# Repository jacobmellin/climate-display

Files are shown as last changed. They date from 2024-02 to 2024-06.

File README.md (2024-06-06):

# 3D Printed Room Climate Display/Controller based on ESP32/Arduino

Let's [Stoßlüft](https://www.youtube.com/watch?v=y79x2q360W8)!

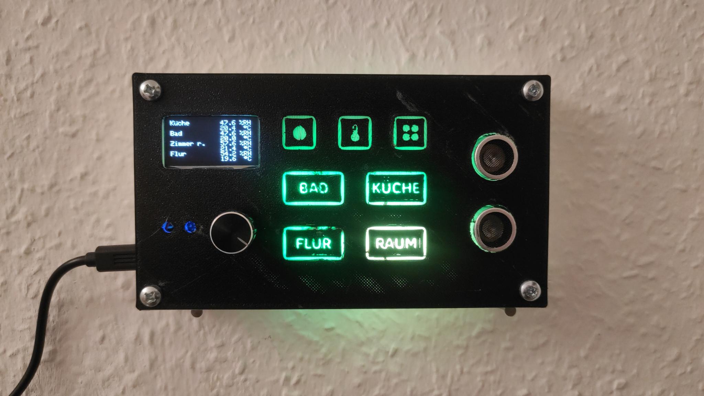
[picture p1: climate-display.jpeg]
Climate Display: preview image of printed device


The DIY Climate Display/Controller thing can do the following:

- Shows Temperature and Relative Humidity information for 4 different rooms at once!
- Can be controlled via MQTT/WiFi, so you can for example setup Home Assistant to set Temperature/Humidity Information
- Will light colored LEDs to tell you when Humidity/Temperature in a room rises above a certain threshold (e. g. Yellow: 57%, Red: 60%).
- Notifies you when you forget to close the windows
- Allows you to set the temperature for your smart thermostats via MQTT

## Components

| Qty. | Component Type | Specific Component used | Est. Price (USD) | Est. Price (€) | Example Shop link (DE) | |
|---|---|---|---|---|---|---|
| 2m | Wire in 3 different colors | | | | | |
|  1x  | ESP32 Development Board | ESP32 Lolin32 Lite | | € 8,99 | https://www.az-delivery.de/en/products/esp32-lolin-lolin32 | |
|  1x  | Ultrasonic Distance Sensor | HC-SR04 | | | | |
|  1x  | OLED Display | SH1106 (128x64) | | | | |
|  7x  | Addressible RGB LED | WSB2812B | | | | |
|  1x  | Rotary Encoder | | | | | |
|  2x  | Push Button (optional) | | | | | |
| 2x | 1K Metal Film resistor | | | | | |
| 1x | USB Power Supply / Micro USB Cable | | | | | |

## Printing & Assembly

TODO

## Configuring & Programming

TODO

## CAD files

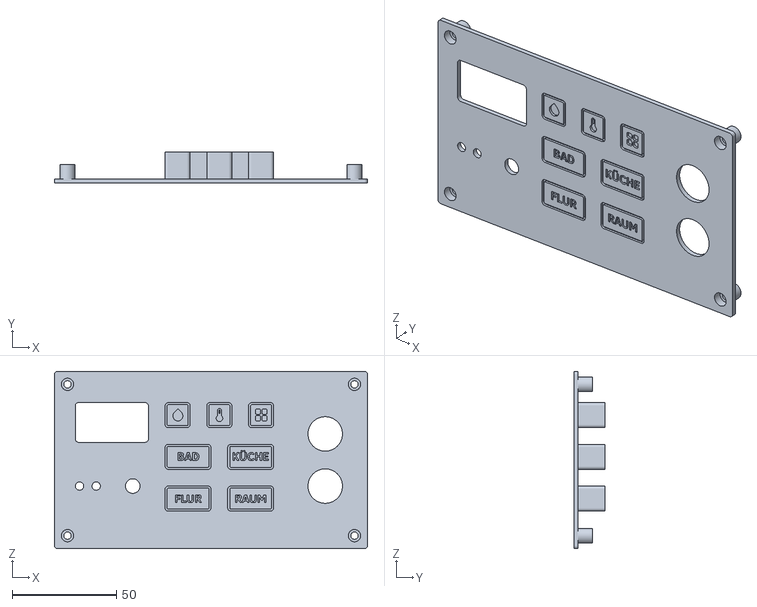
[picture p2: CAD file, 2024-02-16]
cad/ClimateDisplay-Cover.stl
150.0 x 15.0 x 85.0

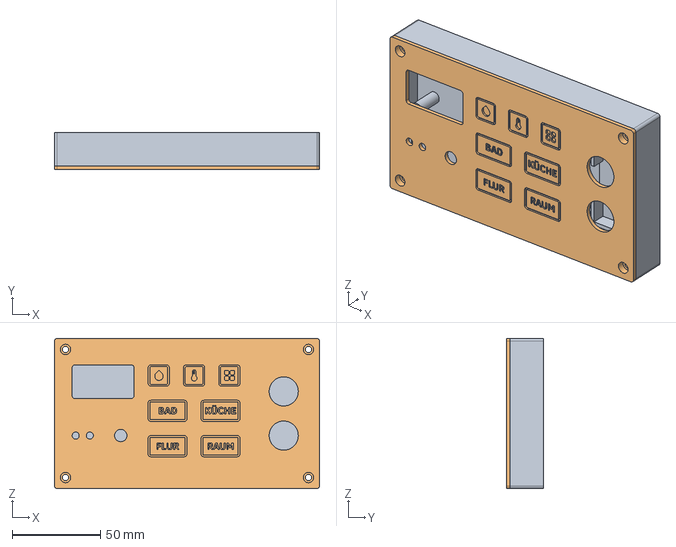
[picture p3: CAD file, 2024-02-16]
cad/ClimateDisplay.FCStd
150.0 x 21.0 x 85.0 mm
Cover

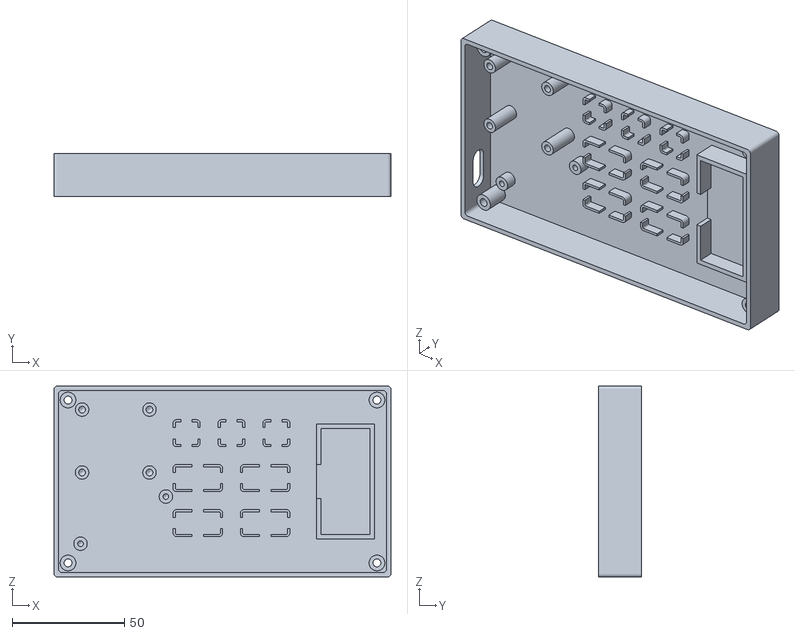
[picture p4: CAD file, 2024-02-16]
cad/ClimateDisplay-Box.stl
150.0 x 19.0 x 85.0

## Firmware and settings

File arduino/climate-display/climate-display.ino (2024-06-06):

#include <WiFi.h>
#include <WiFiClient.h>
#include <WebServer.h>
#include <ESPmDNS.h>
#include <Update.h>
#include <PubSubClient.h>
#include <SPI.h>
#include <Wire.h>
#include <Adafruit_GFX.h>
#include <Adafruit_SH110X.h>
#include <InputDebounce.h>
#include <NewEncoder.h>
#include <HCSR04.h>
#include <arduino-timer.h>

#include <FastLED.h>

const char* host = "esp32";
const char* ssid = "AhoyThereCastaways";
const char* password = "97755056664745005086";

const char* mqtt_server = "192.168.178.43";

#include "web.h"
#include "ClimateDisplay.h"

#define LED_PIN 2
#define NUM_LEDS 7
#define ROTARY_PIN_A 16
#define ROTARY_PIN_B 17
#define BUTTON1_PIN 18
#define US_SENSOR_PIN_ECHO 15
#define US_SENSOR_PIN_TRIG 13
#define PIN_SCK 22
#define PIN_SDA 19

#define SCREEN_WIDTH 128
#define SCREEN_HEIGHT 64
#define OLED_RESET -1
#define SCREEN_ADDRESS 0x3C

#define BUTTON_DEBOUNCE_DELAY 50

auto timer = timer_create_default();

Adafruit_SH1106G display(SCREEN_WIDTH, SCREEN_HEIGHT, &Wire, OLED_RESET);

WebServer server(80);
CRGB leds[NUM_LEDS];
ClimateDisplay climateDisplay(leds, &display);

NewEncoder encoder(ROTARY_PIN_A, ROTARY_PIN_B, -20, 20, 0, 0);
int16_t prevEncoderValue;

static InputDebounce button1;

HCSR04 hc(US_SENSOR_PIN_TRIG, US_SENSOR_PIN_ECHO);
float hcCurrentDist;

WiFiClient espClient;
PubSubClient client(espClient);
long lastMsg = 0;
char msg[50];
int value = 0;

void callback(char* topic, byte* payload, unsigned int length) {
    Serial.print("Message arrived [");
    Serial.print(topic);
    Serial.print("] ");
    for (int i = 0; i < length; i++) {
        Serial.print((char)payload[i]);
    }
    Serial.println();

    // TODO: Do a better job of parsing this
    if(std::string(topic) == "climatedisplay/kitchen/humidity") {
        float humidity = atof((char*)payload);
        climateDisplay.setRoomHumidity(Room::Kitchen, atof((char*)payload));
    } else if(std::string(topic) == "climatedisplay/kitchen/temperature") {
        float temperature = atof((char*)payload);
        climateDisplay.setRoomTemperature(Room::Kitchen, atof((char*)payload));
    } else if(std::string(topic) == "climatedisplay/bathroom/humidity") {
        float humidity = atof((char*)payload);
        climateDisplay.setRoomHumidity(Room::Bathroom, atof((char*)payload));
    } else if(std::string(topic) == "climatedisplay/bathroom/temperature") {
        float temperature = atof((char*)payload);
        climateDisplay.setRoomTemperature(Room::Bathroom, atof((char*)payload));
    } else if(std::string(topic) == "climatedisplay/bedroom/humidity") {
        float humidity = atof((char*)payload);
        climateDisplay.setRoomHumidity(Room::Bedroom, atof((char*)payload));
    } else if(std::string(topic) == "climatedisplay/bedroom/temperature") {
        float temperature = atof((char*)payload);
        climateDisplay.setRoomTemperature(Room::Bedroom, atof((char*)payload));
    } else if(std::string(topic) == "climatedisplay/corridor/humidity") {
        float humidity = atof((char*)payload);
        climateDisplay.setRoomHumidity(Room::Corridor, atof((char*)payload));
    } else if(std::string(topic) == "climatedisplay/corridor/temperature") {
        float temperature = atof((char*)payload);
        climateDisplay.setRoomTemperature(Room::Corridor, atof((char*)payload));
    }
}

void reconnect() {
    // Loop until we're reconnected
    while (!client.connected()) {
        Serial.print("Attempting MQTT connection...");
        // Attempt to connect
        if (client.connect("ESP32Client", "mosquitto", "mosquitto")) {
            Serial.println("connected");

            client.subscribe("climatedisplay/kitchen/humidity");
            client.subscribe("climatedisplay/kitchen/temperature");
            client.subscribe("climatedisplay/bedroom/humidity");
            client.subscribe("climatedisplay/bedroom/temperature");
            client.subscribe("climatedisplay/bathroom/humidity");
            client.subscribe("climatedisplay/bathroom/temperature");
            client.subscribe("climatedisplay/corridor/humidity");
            client.subscribe("climatedisplay/corridor/temperature");
        } else {
            Serial.print("failed, rc=");
            Serial.print(client.state());
            Serial.println(" try again in 5 seconds");
            // Wait 5 seconds before retrying
            delay(5000);
        }
    }
}

void knobCallback(long value) {
    Serial.printf("Value: %i\n", value);
}

/*
 * setup function
 */
void setup(void) {
   pinMode(2, OUTPUT);
   FastLED.addLeds<WS2812B, LED_PIN, GRB>(leds, NUM_LEDS);

  Serial.begin(115200);

  // Connect to WiFi network
  WiFi.begin(ssid, password);
  Serial.println("");

  // Wait for connection
  while (WiFi.status() != WL_CONNECTED) {
    delay(500);
    Serial.print(".");
  }
  Serial.println("");
  Serial.print("Connected to ");
  Serial.println(ssid);
  Serial.print("IP address: ");
  Serial.println(WiFi.localIP());

  // MQTT Setup
  client.setServer(mqtt_server, 1883);
  client.setCallback(callback);

  /*use mdns for host name resolution*/
  if (!MDNS.begin(host)) { //http://esp32.local
    Serial.println("Error setting up MDNS responder!");
    while (1) {
      delay(1000);
    }
  }
  Serial.println("mDNS responder started");
  /*return index page which is stored in serverIndex */
  server.on("/", HTTP_GET, []() {
    server.sendHeader("Connection", "close");
    server.send(200, "text/html", loginIndex);
  });
  server.on("/serverIndex", HTTP_GET, []() {
    server.sendHeader("Connection", "close");
    server.send(200, "text/html", serverIndex);
  });
  /*handling uploading firmware file */
  server.on("/update", HTTP_POST, []() {
    server.sendHeader("Connection", "close");
    server.send(200, "text/plain", (Update.hasError()) ? "FAIL" : "OK");
    ESP.restart();
  }, []() {
    HTTPUpload& upload = server.upload();
    if (upload.status == UPLOAD_FILE_START) {
      Serial.printf("Update: %s\n", upload.filename.c_str());
      if (!Update.begin(UPDATE_SIZE_UNKNOWN)) { //start with max available size
        Update.printError(Serial);
      }
    } else if (upload.status == UPLOAD_FILE_WRITE) {
      /* flashing firmware to ESP*/
      if (Update.write(upload.buf, upload.currentSize) != upload.currentSize) {
        Update.printError(Serial);
      }
    } else if (upload.status == UPLOAD_FILE_END) {
      if (Update.end(true)) { //true to set the size to the current progress
        Serial.printf("Update Success: %u\nRebooting...\n", upload.totalSize);
      } else {
        Update.printError(Serial);
      }
    }
  });

  server.begin();

  // MQTT and Web Timers
  timer.every(1, [](void *arg) -> bool {
    server.handleClient();
    if (!client.connected()) {
      reconnect();
    }
    client.loop();
    return true;
  });


  // Setup OLED
  Wire.begin(PIN_SCK, PIN_SDA);
  if(!display.begin(SCREEN_ADDRESS, true)) {
    Serial.println(F("SH1106: Allocation failed"));
    for(;;);
  }

  // Setup Button
  pinMode(BUTTON1_PIN, INPUT);
  button1.registerCallbacks(nullptr, [](uint8_t pin) {
  });
  button1.setup(BUTTON1_PIN, BUTTON_DEBOUNCE_DELAY, InputDebounce::PIM_INT_PULL_UP_RES);
  timer.every(3, [](void *arg) -> bool {
      unsigned long currentMillis = millis();
      button1.process(currentMillis);
      return true;
  });

  // Setup Climate Display
  climateDisplay.setRoomHumidity(Room::Bedroom, 80);
  climateDisplay.setRoomHumidity(Room::Corridor, 80);

  // Setup rotary encoder
  pinMode(ROTARY_PIN_A, INPUT_PULLUP);
  pinMode(ROTARY_PIN_B, INPUT_PULLUP);
  encoder.begin();
  timer.every(10, [](void *arg) -> bool {
    int16_t currentValue;
    NewEncoder::EncoderState currentEncoderState;

      if(encoder.getState(currentEncoderState)) {
        Serial.println("Encoder: ");
        currentValue = currentEncoderState.currentValue;

        // Handle big jumps
        if(currentValue > (prevEncoderValue + 1)) {
            currentValue = prevEncoderValue + 1;
        } else if(currentValue < (prevEncoderValue - 1)) {
            currentValue = prevEncoderValue - 1;
        }

        prevEncoderValue = currentValue;
        Serial.println(currentValue);
      }     
      return true;
    });

    // Ultrasonic Distance Sensor
    timer.every(250, [](void *arg) -> bool {
      float dist = hc.dist();
      climateDisplay.setUserDistance(dist);
      climateDisplay.loop();
      Serial.println(hc.dist());
      return true;
    });

    // Display loop
    timer.every(50, [](void*arg) -> bool {
         climateDisplay.loop();
         return true;
    });

}

void loop(void) {
  timer.tick();
}

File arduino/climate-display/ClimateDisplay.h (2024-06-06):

#include <map>
#include <FastLED.h>
#include <Adafruit_GFX.h>
#include <Adafruit_SH110X.h>
#include <string>
#include <iomanip>
#include <sstream>

#define LED_FADE_DURATION_MS 1000
#define STANDBY_TIMEOUT_MS 10000

enum class Room
{
    Kitchen,
    Bathroom,
    Bedroom,
    Corridor
};

enum class LED
{
    Kitchen,
    Bathroom,
    Bedroom,
    Corridor,
    Window,
    Humidity,
    Temperature
};

class ClimateDisplay {
    private:
        struct RoomData {
            Room room;
            const char* name;
            float temperature;
            float humidity;
            bool windowOpen;
            LED led;
        };

        struct LEDData {
            int ledIndex;
            CRGB color;
            CRGB fromColor;
            CRGB toColor;
            int fadeStart;
            float fadeProgress;
            bool isFading;
        };

        std::map<Room, RoomData> rooms; 
        std::map<LED, LEDData> displayLEDs;

        CRGB* leds;
        Adafruit_SH1106G* display;
        bool isStandby = false;
        float humidityWarningThreshold = 55;
        float humiditiyCriticalThreshold = 60;
        float temperatureCriticalThreshold = 19;
        float userDistance = 0;
        float userDistanceThreshold = 40;

        float startWakeTime = 0;

        void replaceSpecialChars(const char* text) {
            for (int i = 0; i < sizeof(text); i++) {
            }
        }

        void handleLEDFade() {
            for(auto& led : displayLEDs) {
                if(led.second.isFading) {
                    led.second.fadeProgress = 
                        float(millis() - led.second.fadeStart) / LED_FADE_DURATION_MS;
                    if(led.second.fadeProgress >= 1) {
                        led.second.isFading = false;
                        led.second.color = led.second.toColor;
                    } else {
                        led.second.color = blend(
                                led.second.fromColor,
                                led.second.toColor,
                                led.second.fadeProgress*255);
                    }
                    leds[led.second.ledIndex] = led.second.color;
                    FastLED.show();
                }
            }
        }

    public:
        ClimateDisplay(CRGB* leds, Adafruit_SH1106G* display) {
            this->leds = leds;
            this->display = display;

            displayLEDs[LED::Kitchen] = LEDData();
            displayLEDs[LED::Kitchen].ledIndex = 3;
            displayLEDs[LED::Kitchen].color = CRGB::Black;

            displayLEDs[LED::Bathroom] = LEDData();
            displayLEDs[LED::Bathroom].ledIndex = 4;
            displayLEDs[LED::Bathroom].color = CRGB::Black;


            displayLEDs[LED::Corridor] = LEDData();
            displayLEDs[LED::Corridor].ledIndex = 5;
            displayLEDs[LED::Corridor].color = CRGB::Black;

            displayLEDs[LED::Bedroom] = LEDData();
            displayLEDs[LED::Bedroom].ledIndex = 6;
            displayLEDs[LED::Bedroom].color = CRGB::Black;

            displayLEDs[LED::Window] = LEDData();
            displayLEDs[LED::Window].ledIndex = 2;
            displayLEDs[LED::Window].color = CRGB::Black;

            displayLEDs[LED::Humidity] = LEDData();
            displayLEDs[LED::Humidity].ledIndex = 0;
            displayLEDs[LED::Humidity].color = CRGB::Black;
            
            displayLEDs[LED::Temperature] = LEDData();
            displayLEDs[LED::Temperature].ledIndex = 0;
            displayLEDs[LED::Temperature].color = CRGB::Black;

            rooms[Room::Kitchen] = RoomData();
            rooms[Room::Kitchen].room = Room::Kitchen;
            rooms[Room::Kitchen].led = LED::Kitchen;
            rooms[Room::Kitchen].name = "K\201che";

            rooms[Room::Bathroom] = RoomData();
            rooms[Room::Bathroom].room = Room::Bathroom;
            rooms[Room::Bathroom].led = LED::Bathroom;
            rooms[Room::Bathroom].name = "Bad";

            rooms[Room::Bedroom] = RoomData();
            rooms[Room::Bedroom].room = Room::Bedroom;
            rooms[Room::Bedroom].led = LED::Bedroom;
            rooms[Room::Bedroom].name = "Zimmer r.";

            rooms[Room::Corridor] = RoomData(); 
            rooms[Room::Corridor].room = Room::Corridor;
            rooms[Room::Corridor].led = LED::Corridor;
            rooms[Room::Corridor].name = "Flur";
        };


        void setRoomTemperature(Room room, float temperature) {
            rooms[room].temperature = temperature;
            updateLEDs();
            drawScreen();
        };

        void setRoomHumidity(Room room, float humidity) {
            rooms[room].humidity = humidity;
            updateLEDs();
            drawScreen();
        };

        void setRoomWindowOpen(Room room, bool open) {
            rooms[room].windowOpen = open;
        };

        void setStandby(bool standby) {
            isStandby = standby;
            if(!isStandby) {
                // Display has been woken up     
               startWakeTime = millis();
            }
            updateLEDs();
            drawScreen();
        };

        void setHumidityWarningThreshold(float threshold) {
            humidityWarningThreshold = threshold;
        };

        void setHumidityCriticalThreshold(float threshold) {
            humiditiyCriticalThreshold = threshold; 
        };

        void setUserDistance(float distance) {
            userDistance = distance;
        }

        void fadeDisplayLED(LED led, CRGB target) {
            if(!displayLEDs[led].isFading) {
                if(displayLEDs[led].color == target) {
                    return;
                }
                displayLEDs[led].fromColor = displayLEDs[led].color;
                displayLEDs[led].toColor = target;
                displayLEDs[led].isFading = true;
                displayLEDs[led].fadeProgress = 0;
                displayLEDs[led].fadeStart = millis();
            } else {
                if(displayLEDs[led].toColor != target) {
                    displayLEDs[led].toColor = target;
                    displayLEDs[led].fromColor = displayLEDs[led].color;
                    displayLEDs[led].fadeProgress = 0;
                    displayLEDs[led].fadeStart = millis();
                }
            }
        };

        void drawScreen() {
          display->clearDisplay();

          if(isStandby) {
            display->display();
            return;
          }

          display->setTextSize(1);
          display->setTextColor(SH110X_WHITE);
          display->setCursor(0,1);
          display->cp437(true);

          bool first = true;

          for (auto room : rooms) {
            if(first) {
                first = false;
            } else {
                display->print("\n");
            }

            std::stringstream label;
            label << std::left << std::setw(10) << room.second.name;
            display->print(label.str().c_str());
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

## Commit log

2024-02-03 Allow leds to be faded
2024-02-04 Update display formatting; enable button
2024-02-04 Begin setting up rotary encoder
2024-02-05 Add timers
2024-02-05 Set standby based on ultrasonic sensor data
2024-02-05 Move arduino sketch to subfolder
2024-02-05 Begin FreeCad construction
    [ClimateDisplay.FCStd]
2024-02-05 Add screwholes and screw standoffs
    [ClimateDisplay.FCStd]
2024-02-05 Model front with standoffs
    [ClimateDisplay.FCStd]
2024-02-07 Add icons to cad
    [ClimateDisplay.FCStd]
2024-02-07 Finish first iteration of Case
    [ClimateDisplay-Box.stl]
2024-02-07 Make Cover standoffs same diameter as Box standoffs
2024-02-13 Fix dimensions and positioning of screwholes
2024-02-16 Add new indicator light fixtures
    [ClimateDisplay-Box.stl, ClimateDisplay.FCStd]
2024-02-16 Add LED fixtures on back
    [ClimateDisplay-Box.stl, ClimateDisplay-Cover.stl, ClimateDisplay.FCStd]
2024-02-16 Add missing pocket clones
    [ClimateDisplay-Cover.stl, ClimateDisplay.FCStd]
